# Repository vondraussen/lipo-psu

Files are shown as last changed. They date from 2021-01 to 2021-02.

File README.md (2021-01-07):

# LIPO PSU
2S lithium polymer battery power supply for micro controller projects. The main idea is to use it for long running low power micro controller projects.

This is work in progress...

## Requirements
- Voltage output 3.3 V
- Current ouput up to 500 mA
- low quiescent current < 10 uA
- cell protection
- discharge/undervoltage protection

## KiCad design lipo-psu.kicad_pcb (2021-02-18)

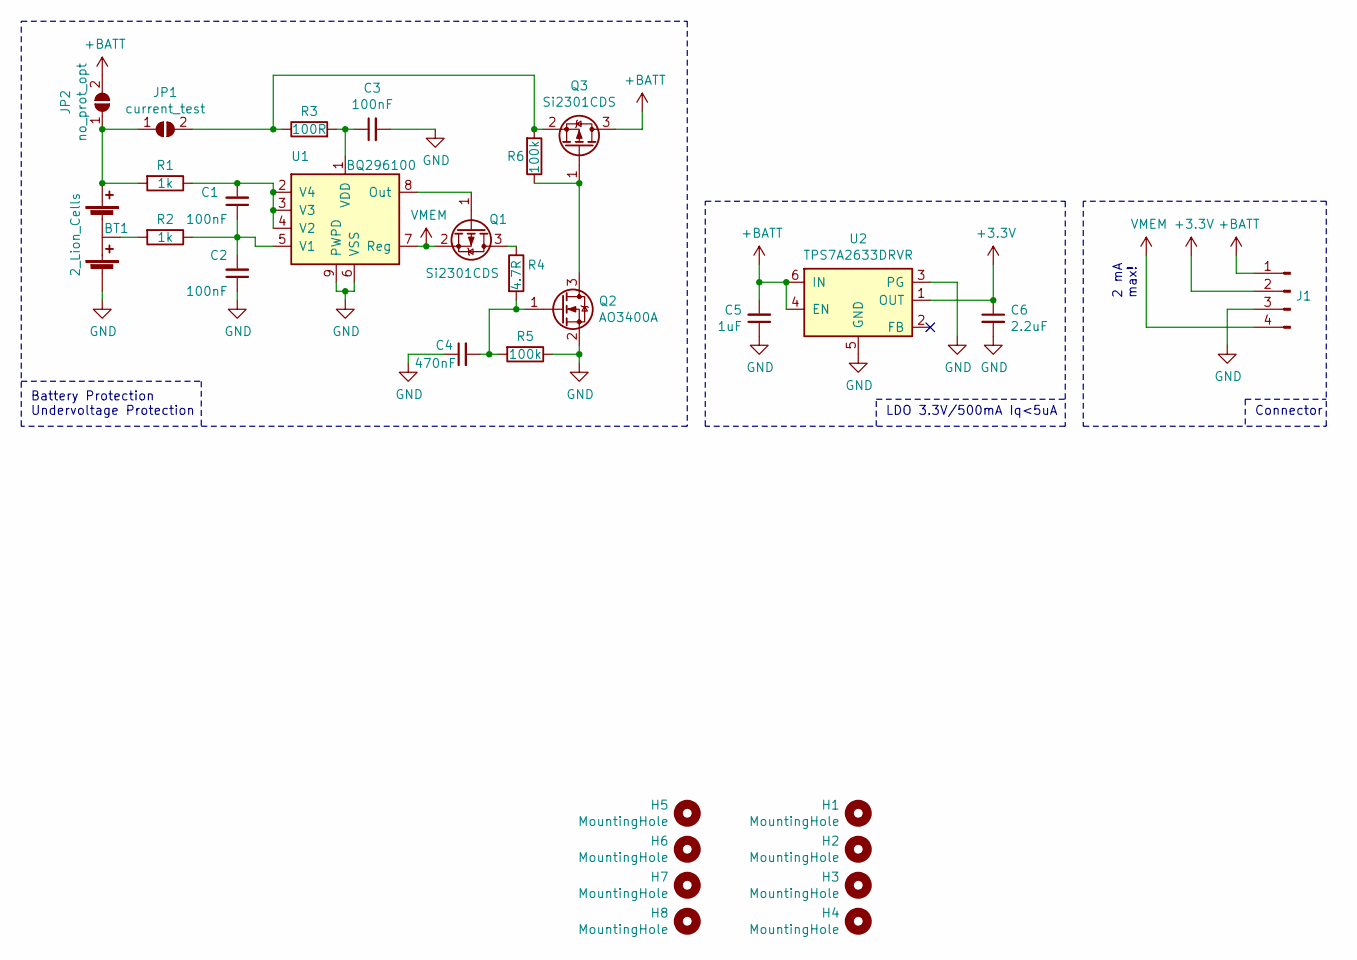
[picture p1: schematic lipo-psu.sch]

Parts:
BT1: 2_Lion_Cells; BatteryHolder_Keystone_1048P_2x18650; Digikey 36-1048P-ND
C1, C2, C3: 100nF; C_0603_1608Metric; JLCPCB CC0603KRX7R9BB104
C4: 470nF; C_0603_1608Metric; JLCPCB CL10B474KA8NNNC
C5: 1uF; C_0603_1608Metric; JLCPCB CL10A105KB8NNNC
C6: 2.2uF; C_1206_3216Metric; JLCPCB CL31B225KBHNNNE
H1, H2, H3, H4, H5, H6, H7, H8: MountingHole; MountingHole_2.5mm
J1: 4Pin; PinHeader_1x04_P2.54mm_Vertical
JP1: current_test; SolderJumper-2_P1.3mm_Open_TrianglePad1.0x1.5mm
JP2: no_prot_opt; SolderJumper-2_P1.3mm_Open_TrianglePad1.0x1.5mm
Q1, Q3: Si2301CDS; SOT-23; JLCPCB SI2301CDS-T1-GE3
Q2: AO3400A; SOT-23; JLCPCB AO3400A
R1, R2: 1k; R_0603_1608Metric; JLCPCB 0603WAF1001T5E
R3: 100R; R_0603_1608Metric; JLCPCB 0603WAF1000T5E
R4: 4.7R; R_0603_1608Metric; JLCPCB 0603WAF470KT5E
R5, R6: 100k; R_0603_1608Metric; JLCPCB 0603WAF1003T5E
U1: BQ296100; WSON-8-1EP_2x2mm_P0.5mm_EP0.9x1.6mm; Digikey 296-50964-1-ND
U2: TPS7A2633DRVR; WSON-6-1EP_2x2mm_P0.65mm_EP1x1.6mm; Digikey 296-TPS7A2633DRVRCT-ND

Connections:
+3V3: C6.1, J1.2, U2.1 (OUT)
+BATT: C5.2, J1.1, JP2.2 (B), Q3.3 (D), U2.4 (EN), U2.6 (IN)
GND: BT1.3 (-), C2.1, C3.2, C4.1, C5.1, C6.2, J1.3, Q2.2 (S), R5.1, U1.6 (VSS), U1.9 (PWPD), U2.3 (PG), U2.5 (GND), U2.7 (GND)
unnamed: BT1.1 (+), JP1.1 (A), JP2.1 (A), R1.2
unnamed: BT1.2 (-), BT1.4 (+), R2.2
unnamed: C1.1, C2.2, R2.1, U1.5 (V1)
unnamed: C1.2, R1.1, U1.2 (V4), U1.3 (V3), U1.4 (V2)
unnamed: C3.1, R3.2, U1.1 (VDD)
unnamed: C4.2, Q2.1 (G), R4.2, R5.2
unnamed: JP1.2 (B), Q3.2 (S), R3.1, R6.2
unnamed: Q1.1 (G), U1.8 (Out)
unnamed: Q1.3 (D), R4.1
unnamed: Q2.3 (D), Q3.1 (G), R6.1
VMEM: J1.4, Q1.2 (S), U1.7 (Reg)

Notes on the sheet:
LDO 3.3V/500mA Iq<5uA
Battery Protection Undervoltage Protection
2 mA max!
Connector

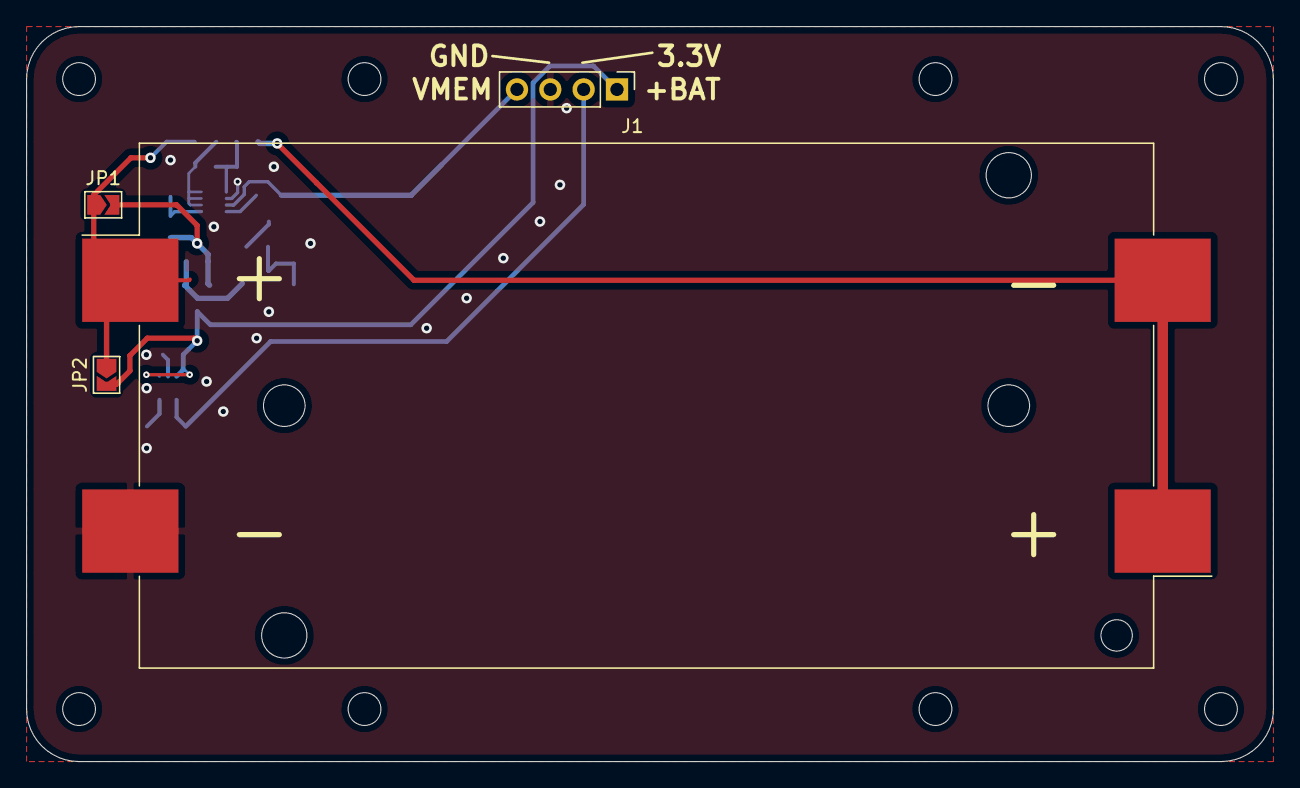
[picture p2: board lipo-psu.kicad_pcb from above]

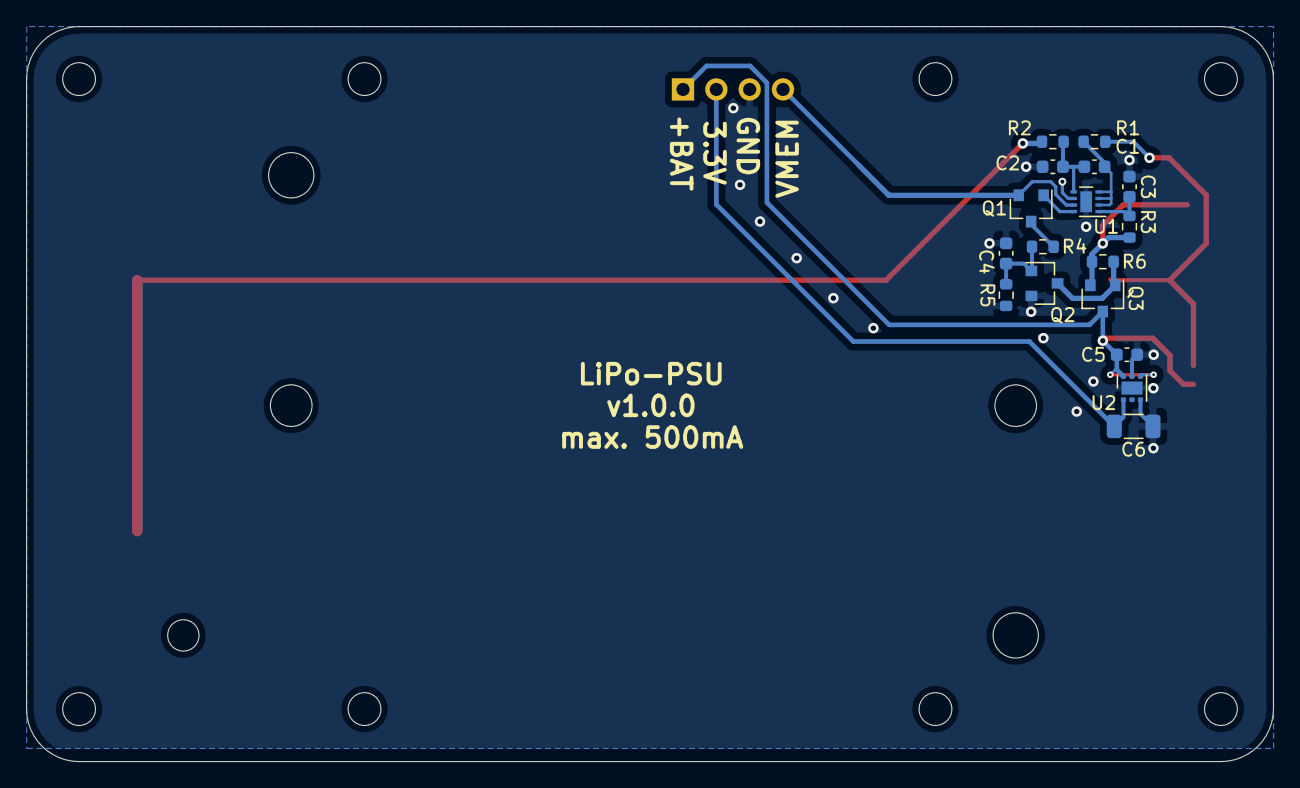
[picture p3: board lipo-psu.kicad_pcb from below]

Board: 2 copper layers, 95.0 x 56.0 mm, 29 parts (17 on the bottom side), 14 nets.
